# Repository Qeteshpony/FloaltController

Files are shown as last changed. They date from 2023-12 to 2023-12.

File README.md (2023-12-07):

# FLOALT Controller





[Schematics](https://qeteshpony.github.io/FloaltController/)

A custom, ESP32 based controller for the 30 x 90 cm IKEA FLOALT LED light panel. This probably works with other sizes of the panel as well but i can't test this since I don't own any of them. 

I created this since my original controller got fried by a thunderstorm and IKEA does not sell these anymore in Europe. 

As a side effect this allows way better control over the panel than the original controller which kept the light very bright even at lowest settings. The board is created with KiCad 7 and with production and assembly by JLCPCB in mind. Some components have to be purchased elsewhere and manually soldered. 

The controller is powered by a 24VDV 2.5A power supply, though 1.5A are enough if you never run both warm and cold white on full power at the same time. I use ESPHome with the included code to control this, which takes care of that automatically.

The included .stl file is a simple frame to glue the board to the back of the panel.

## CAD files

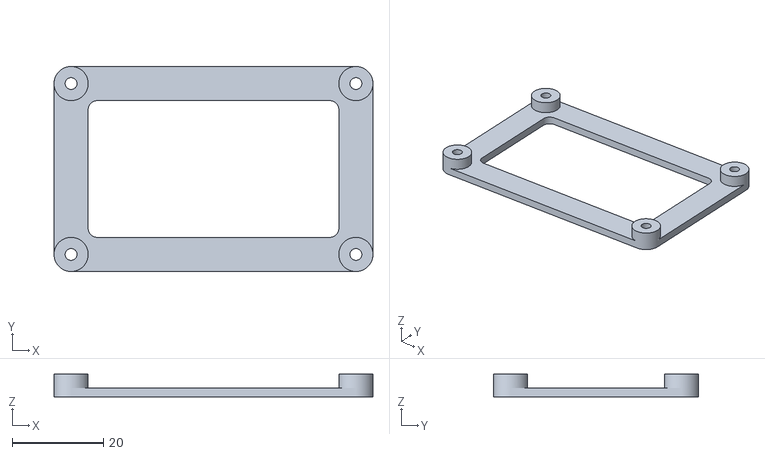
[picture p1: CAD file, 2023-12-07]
frame.stl
70.0 x 45.0 x 5.00

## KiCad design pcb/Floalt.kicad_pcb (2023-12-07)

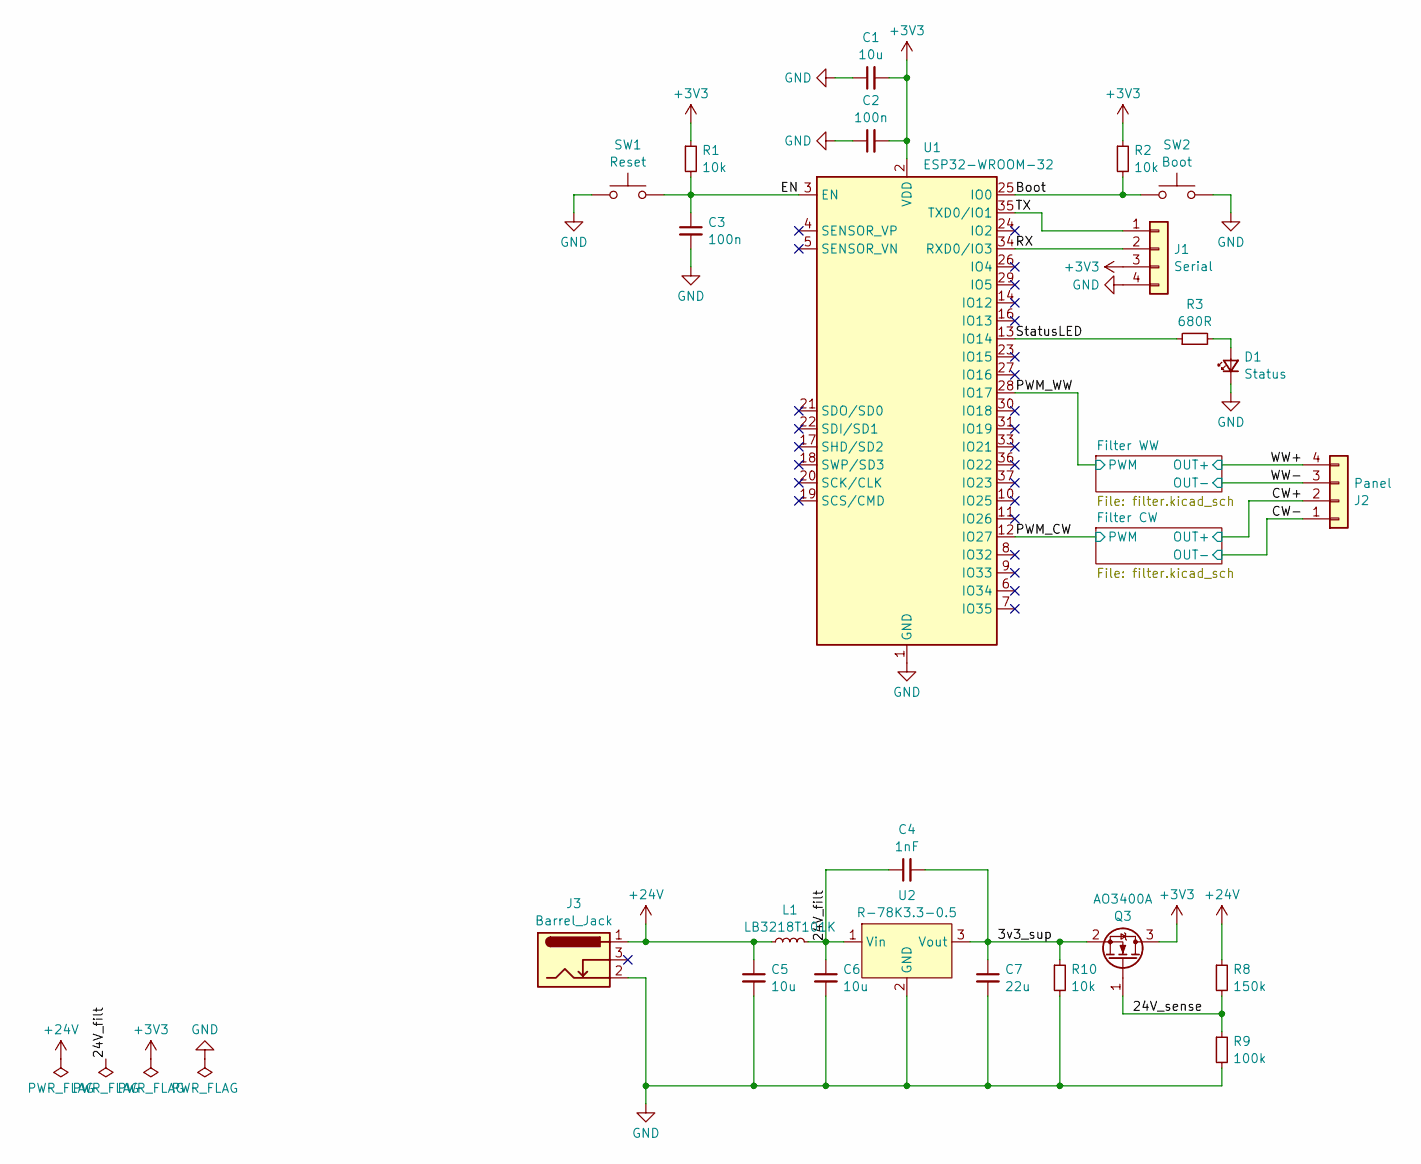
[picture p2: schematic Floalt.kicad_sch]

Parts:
C1: 10u; C_0402_1005Metric; LCSC C15525
C2, C3: 100n; C_0402_1005Metric; LCSC C307331
C4: 1nF; C_0402_1005Metric; LCSC C1523
C5, C6: 10u; C_1206_3216Metric; LCSC C13585
C7: 22u; C_1206_3216Metric; LCSC C12891
D1: Status; LED_0603_1608Metric; LCSC C2286
J1: Serial; PinSocket_1x04_P2.54mm_Vertical
J2: Panel; JST_VH_B4PS-VH_1x04_P3.96mm_Horizontal
J3: Barrel_Jack; BarrelJack_Horizontal
L1: LB3218T101K; L_1206_3216Metric_Pad1.22x1.90mm_HandSolder
Q3: AO3400A; SOT-23; LCSC C20917
R1, R2, R10: 10k; R_0402_1005Metric; LCSC C25744
R3: 680R; R_0402_1005Metric; LCSC C25130
R8: 150k; R_0402_1005Metric; LCSC C25755
R9: 100k; R_0402_1005Metric; LCSC C25741
SW1: Reset; SW_Push_1P1T_XKB_TS-1187A; LCSC C318884
SW2: Boot; SW_Push_1P1T_XKB_TS-1187A; LCSC C318884
U1: ESP32-WROOM-32
U2: R-78K3.3-0.5; LME78_1.0-Series

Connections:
+3V3: C1.2, C2.2, J1.3, Q3.3 (D), R1.1, R2.1, U1.2 (VDD)
+24V: C5.1, J3.1, L1.1, R8.1; also elsewhere on the board
/3v3_sup: C4.2, C7.1, Q3.2 (S), R10.1, U2.3 (Vout)
/24V_filt: C4.1, C6.1, L1.2, U2.1 (Vin)
/24V_sense: Q3.1 (G), R8.2, R9.1
/Boot: R2.2, SW2.1, U1.25 (IO0)
/CW+: J2.2; also elsewhere on the board
/CW-: J2.1; also elsewhere on the board
/EN: C3.1, R1.2, SW1.2, U1.3 (EN)
/PWM_CW: U1.12 (IO27); also elsewhere on the board
/PWM_WW: U1.28 (IO17); also elsewhere on the board
/RX: J1.2, U1.34 (RXD0/IO3)
/StatusLED: R3.1, U1.13 (IO14)
/TX: J1.1, U1.35 (TXD0/IO1)
/WW+: J2.4; also elsewhere on the board
/WW-: J2.3; also elsewhere on the board
GND: C1.1, C2.1, C3.2, C5.2, C6.2, C7.2, D1.1 (K), J1.4, J3.2, R9.2, R10.2, SW1.1, SW2.2, U1.1 (GND), U1.15 (GND), U1.38 (GND), U1.39 (GND), U2.2 (GND); also elsewhere on the board
unnamed: D1.2 (A), R3.2

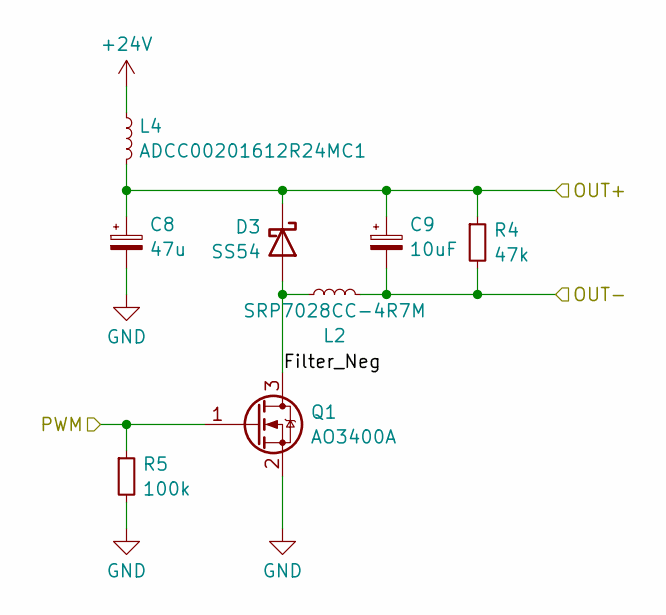
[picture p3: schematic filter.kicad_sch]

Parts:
C8: 47u; CP_Elec_6.3x5.8
C9: 10uF; CP_Elec_5x5.8
D3: SS54; D_SMA; LCSC C22452
L2: SRP7028CC-4R7M; L_Bourns_SRP7028A_7.3x6.6mm
L4: ADCC00201612R24MC1; L_0805_2012Metric_Pad1.15x1.40mm_HandSolder
Q1: AO3400A; SOT-23; LCSC C20917
R4: 47k; R_0805_2012Metric; LCSC C17713
R5: 100k; R_0402_1005Metric; LCSC C25741

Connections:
+24V: L4.1; also elsewhere on the board
/CW+: C8.1, C9.1, D3.1 (K), L4.2, R4.1; also elsewhere on the board
/CW-: C9.2, L2.2, R4.2; also elsewhere on the board
/Filter CW/Filter_Neg: D3.2 (A), L2.1, Q1.3 (D)
/PWM_CW: Q1.1 (G), R5.1; also elsewhere on the board
GND: C8.2, Q1.2 (S), R5.2; also elsewhere on the board

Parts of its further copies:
C10: 47u; CP_Elec_6.3x5.8
C11: 10uF; CP_Elec_5x5.8
D4: SS54; D_SMA; LCSC C22452
L3: SRP7028CC-4R7M; L_Bourns_SRP7028A_7.3x6.6mm
L5: ADCC00201612R24MC1; L_0805_2012Metric_Pad1.15x1.40mm_HandSolder
Q2: AO3400A; SOT-23; LCSC C20917
R6: 47k; R_0805_2012Metric; LCSC C17713
R7: 100k; R_0402_1005Metric; LCSC C25741

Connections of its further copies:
+24V: L5.1; also elsewhere on the board
/Filter WW/Filter_Neg: D4.2 (A), L3.1, Q2.3 (D)
/PWM_WW: Q2.1 (G), R7.1; also elsewhere on the board
/WW+: C10.1, C11.1, D4.1 (K), L5.2, R6.1; also elsewhere on the board
/WW-: C11.2, L3.2, R6.2; also elsewhere on the board
GND: C10.2, Q2.2 (S), R7.2; also elsewhere on the board

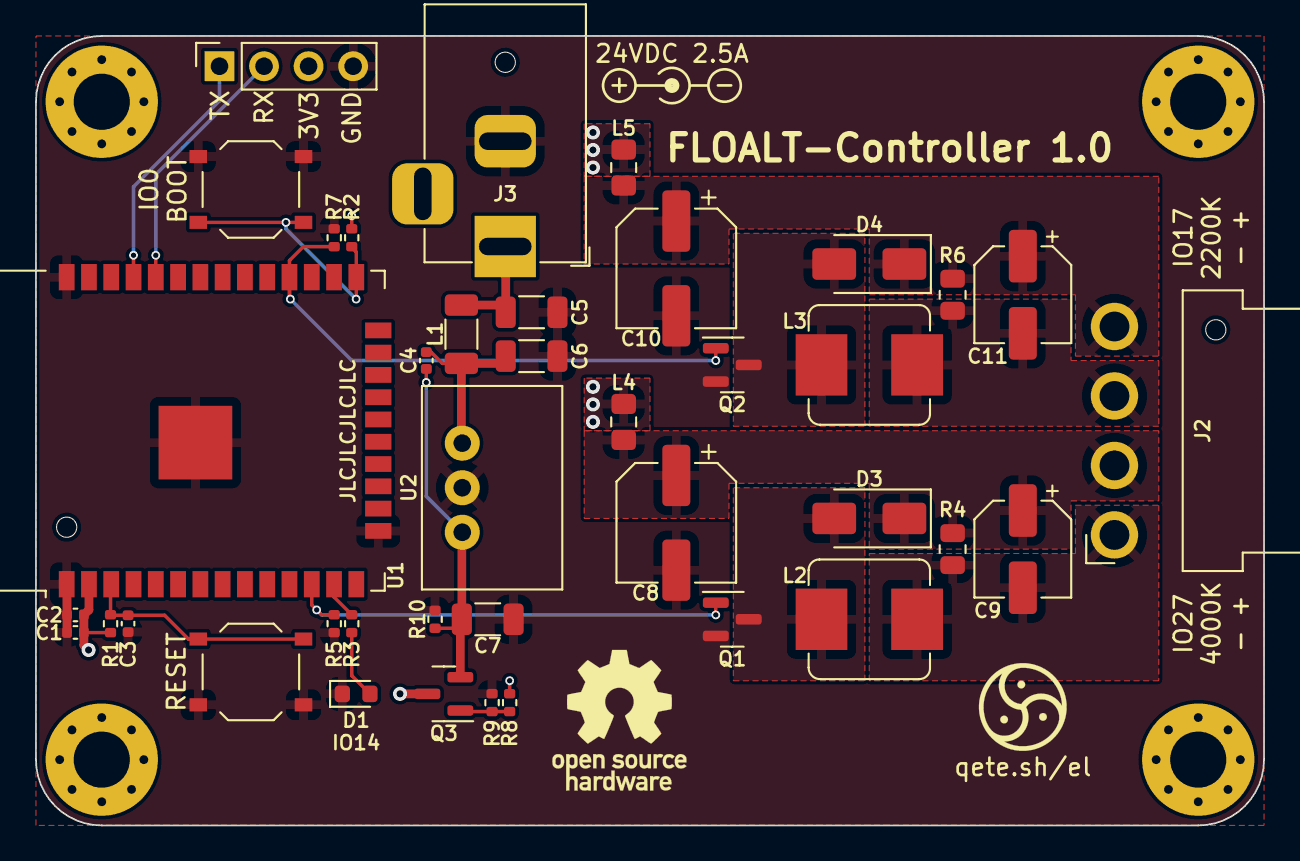
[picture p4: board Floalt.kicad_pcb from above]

Board: 2 copper layers, 70.0 x 45.0 mm, 39 parts (0 on the bottom side), 20 nets.

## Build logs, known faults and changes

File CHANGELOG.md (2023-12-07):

# Changelog

## 1.0.0 (2023-12-07)

### Features

* add ESPHome code ([ca73c7a](https://github.com/Qeteshpony/FloaltController/commit/ca73c7ad4972c343129099356adf6641762aef33))
* initial commit ([46f713d](https://github.com/Qeteshpony/FloaltController/commit/46f713de5ab69781302b69351f61269736c36c6b))

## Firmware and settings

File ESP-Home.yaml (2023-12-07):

status_led:
  pin: 
    number: GPIO14
    inverted: False

output:
  - platform: ledc
    pin: GPIO27
    id: output_cw
    max_power: 1.0
    frequency: 19531
  - platform: ledc
    pin: GPIO17
    id: output_ww
    max_power: 1.0
    frequency: 19531


light:
  - platform: cwww
    name: "Light"
    id: floalt
    icon: mdi:rectangle-outline
    cold_white: output_cw
    warm_white: output_ww
    cold_white_color_temperature: 4000 K
    warm_white_color_temperature: 2200 K
    constant_brightness: True
    default_transition_length: 1.0s
    restore_mode: RESTORE_AND_OFF
    gamma_correct: 1.0
